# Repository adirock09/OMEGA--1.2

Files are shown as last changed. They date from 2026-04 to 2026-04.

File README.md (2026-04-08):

# OMEGA--1.2<br><br>
Screenshot (135)<br><br>

This is a Custom Rp2040 Chip Based MicroPad , It has 9 Switches , a roter encode and a oled screen . We used matrix for switches so it uses less gpio pins and it has 4 layers the rotor key is used to change the layers which is displaced on the screen so in total we have  keys output 9x4=36 + 4 outputs from rotor = 40 Outputs.
## Features

- Based on RP2040 Chip
- Has total 40 Outputs
## Firmware
- Firmware is based on QMK.
### Schematic<br><br>
Screenshot (141)<br><br>

###  PCB Design<br><br>
Screenshot (133)<br><br>
### Case<br><br>
Screenshot (140)

<br><br>

### 3D Design<br><br>
Screenshot (136)
Screenshot (137)
Screenshot (135)<br><br>

#  Bill of Materials (BOM)

##  DigiKey Components

| Qty | Manufacturer Part Number | Description | Unit Price (USD) | Total (USD) |
|-----|---|---|---|---|
| 2 | C0402C105K9PACTU | 1µF 6.3V X5R Capacitor (0402) | 0.08000 | 0.16 |
| 11 | 0402B104K160CT | 0.1µF 16V X7R Capacitor (0402) | 0.00300 | 0.03 |
| 2 | LMK107BBJ106MALT | 10µF 10V X5R Capacitor (0603) | 0.08000 | 0.16 |
| 2 | CL05C330JB5NNNC | 33pF 50V C0G Capacitor (0402) | 0.10000 | 0.20 |
| 1 | USB4215-03-A | USB Type-C Receptacle (USB 2.0) | 0.49000 | 0.49 |
| 2 | RC0402FR-075K1L | 5.1KΩ 1% Resistor (0402) | 0.10000 | 0.20 |
| 2 | ERA-2AEB273X | 27KΩ 0.1% Resistor (0402) | 0.10000 | 0.20 |
| 1 | 18996 | 0.91" OLED Display Module | 1.95 | 1.95 |
| 2 | RMCF0603FT1K00 | 1KΩ 1% Resistor (0603) | 0.10000 | 0.20 |
| 1 | RC0201FR-0710KL | 10KΩ 1% Resistor (0201) | 0.10000 | 0.10 |
| 1 | SW-PB9-AB00AQE-5 | Subminiature Pushbutton Switch | 3.39000 | 3.39 |
| 1 | SC0914(13) | RP2040 Microcontroller (QFN-56) | 0.70000 | 0.70 |
| 1 | MCP1700T-3302E/TT | 3.3V 250mA Linear Voltage Regulator | 0.51000 | 0.51 |
| 1 | AT24CS02-SSHM-T | 2Kbit I2C EEPROM | 0.31000 | 0.31 |
| 1 | STDCRA3-8M | 8MHz SMD Crystal | 0.84000 | 0.84 |
| 1 | 183031570409 | M3 Hex Socket Cap Screw | 5.05000 | 5.05 |
| 1 | 5009 | DSA Keycap Set (MX Compatible) | 5.95000 | 5.95 |
| 5 | DV-M30-TH | M3 Heat-Set Thread Insert | 0.18200 | 0.91 |
| 9 | MX2A-71NW | Cherry MX Silent Red Switch | 1.95000 | 17.55 |
| 10 | 1N4148 | Signal Diode 100V 200mA | 0.03900 | 0.39 |
| 1 | 6071183 | Rotary Encoder (BCG13 Series) | 2.44000 | 2.44 |

---

##  Manufacturing & Shipping

| Item | Cost (USD) |
|---|---|
| DigiKey Shipping  | 20.00 |
| JLCPCB – PCB Fabrication + Stencil | 7.01 |
| JLCPCB Shipping - Coupons | 8.16 |

---

#  Total Project Cost

| Category | Cost (USD) |
|---|---|
| DigiKey Components | 41.73 |
| DigiKey Shipping | 20.00 |
| JLCPCB PCB + Stencil | 7.01 |
| JLCPCB Shipping - Coupons | 8.16|
| **Grand Total** | **76.9 USD** |

---

##  Final Total: **$76.9 USD**

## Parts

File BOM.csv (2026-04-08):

Category | Quantity | Manufacturer Part Number | Description | Supplier | Unit Price (USD) | Total (USD)
Component | 2 | C0402C105K9PACTU | 1µF 6.3V X5R Capacitor (0402) | DigiKey.in | 0.08 | 0.16
Component | 11 | 0402B104K160CT | 0.1µF 16V X7R Capacitor (0402) | DigiKey.in | 0.003 | 0.03
Component | 2 | LMK107BBJ106MALT | 10µF 10V X5R Capacitor (0603) | DigiKey.in | 0.08 | 0.16
Component | 2 | CL05C330JB5NNNC | 33pF 50V C0G Capacitor (0402) | DigiKey.in | 0.1 | 0.2
Component | 1 | USB4215-03-A | USB Type-C Receptacle (USB 2.0) | DigiKey.in | 0.49 | 0.49
Component | 2 | RC0402FR-075K1L | 5.1KΩ 1% Resistor (0402) | DigiKey.in | 0.1 | 0.2
Component | 2 | ERA-2AEB273X | 27KΩ 0.1% Resistor (0402) | DigiKey.in | 0.1 | 0.2
Component | 2 | RMCF0603FT1K00 | 1KΩ 1% Resistor (0603) | DigiKey.in | 0.1 | 0.2
Component | 1 | 18996 | 0.91 inch OLED Display Module | robu.in | 1.95 | 1.95
Component | 1 | RC0201FR-0710KL | 10KΩ 1% Resistor (0201) | DigiKey.in | 0.1 | 0.1
Component | 1 | SW-PB9-AB00AQE-5 | Subminiature Pushbutton Switch | DigiKey.in | 3.39 | 3.39
Component | 1 | SC0914(13) | RP2040 Microcontroller (QFN-56) | DigiKey.in | 0.7 | 0.7
Component | 1 | MCP1700T-3302E/TT | 3.3V 250mA Linear Voltage Regulator | DigiKey.in | 0.51 | 0.51
Component | 1 | AT24CS02-SSHM-T | 2Kbit I2C EEPROM | DigiKey.in | 0.31 | 0.31
Component | 1 | STDCRA3-8M | 8MHz SMD Crystal | DigiKey.in | 0.84 | 0.84
Component | 1 | 183031570409 | M3 Hex Socket Cap Screw | DigiKey.in | 5.05 | 5.05
Component | 1 | 5009 | DSA Keycap Set (MX Compatible) | DigiKey.in | 5.95 | 5.95
Component | 5 | DV-M30-TH | M3 Heat-Set Thread Insert | DigiKey.in | 0.182 | 0.91
Component | 9 | MX2A-71NW | Cherry MX Silent Red Switch | DigiKey.in | 1.95 | 17.55
Component | 10 | 1N4148 | Signal Diode 100V 200mA | DigiKey.in | 0.039 | 0.39
Component | 1 | 6071183 | Rotary Encoder (BCG13 Series) | DigiKey.in | 2.44 | 2.44
Service | 1 | DIGIKEY-SHIPPING | DigiKey Shipping - Coupon | DigiKey.in | 20 | 20
Service | 1 | JLCPCB-PCB-STENCIL | JLCPCB PCB + Stencil | JLCPCB | 7.01 | 7.01
Service | 1 | JLCPCB-SHIPPING | JLCPCB Shipping - Coupon | JLCPCB | 8.16 | 8.16
 |  |  | Grand Total |  |  | 76.9

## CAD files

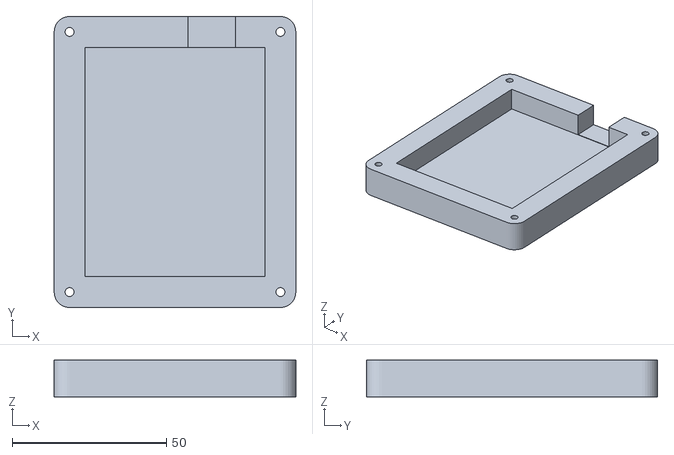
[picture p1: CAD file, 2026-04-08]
OMEGA (Custom Rp2040 Chip MicroPad)/Production/BaseLayer((O)).stl
78.4 x 94.4 x 12.0

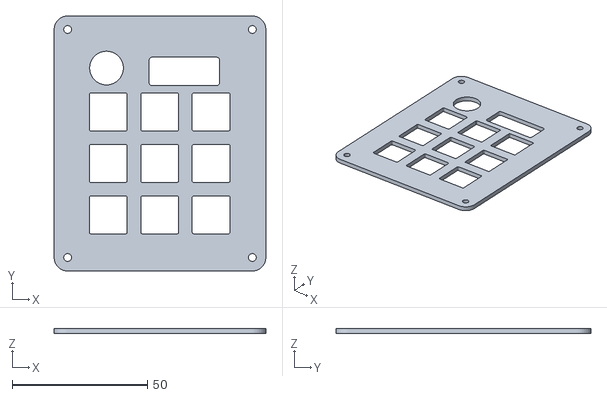
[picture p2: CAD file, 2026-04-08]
OMEGA (Custom Rp2040 Chip MicroPad)/Production/Top Layer.stl
78.4 x 94.4 x 2.00

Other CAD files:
OMEGA (Custom Rp2040 Chip MicroPad)/CAD/OMEGA.f3d

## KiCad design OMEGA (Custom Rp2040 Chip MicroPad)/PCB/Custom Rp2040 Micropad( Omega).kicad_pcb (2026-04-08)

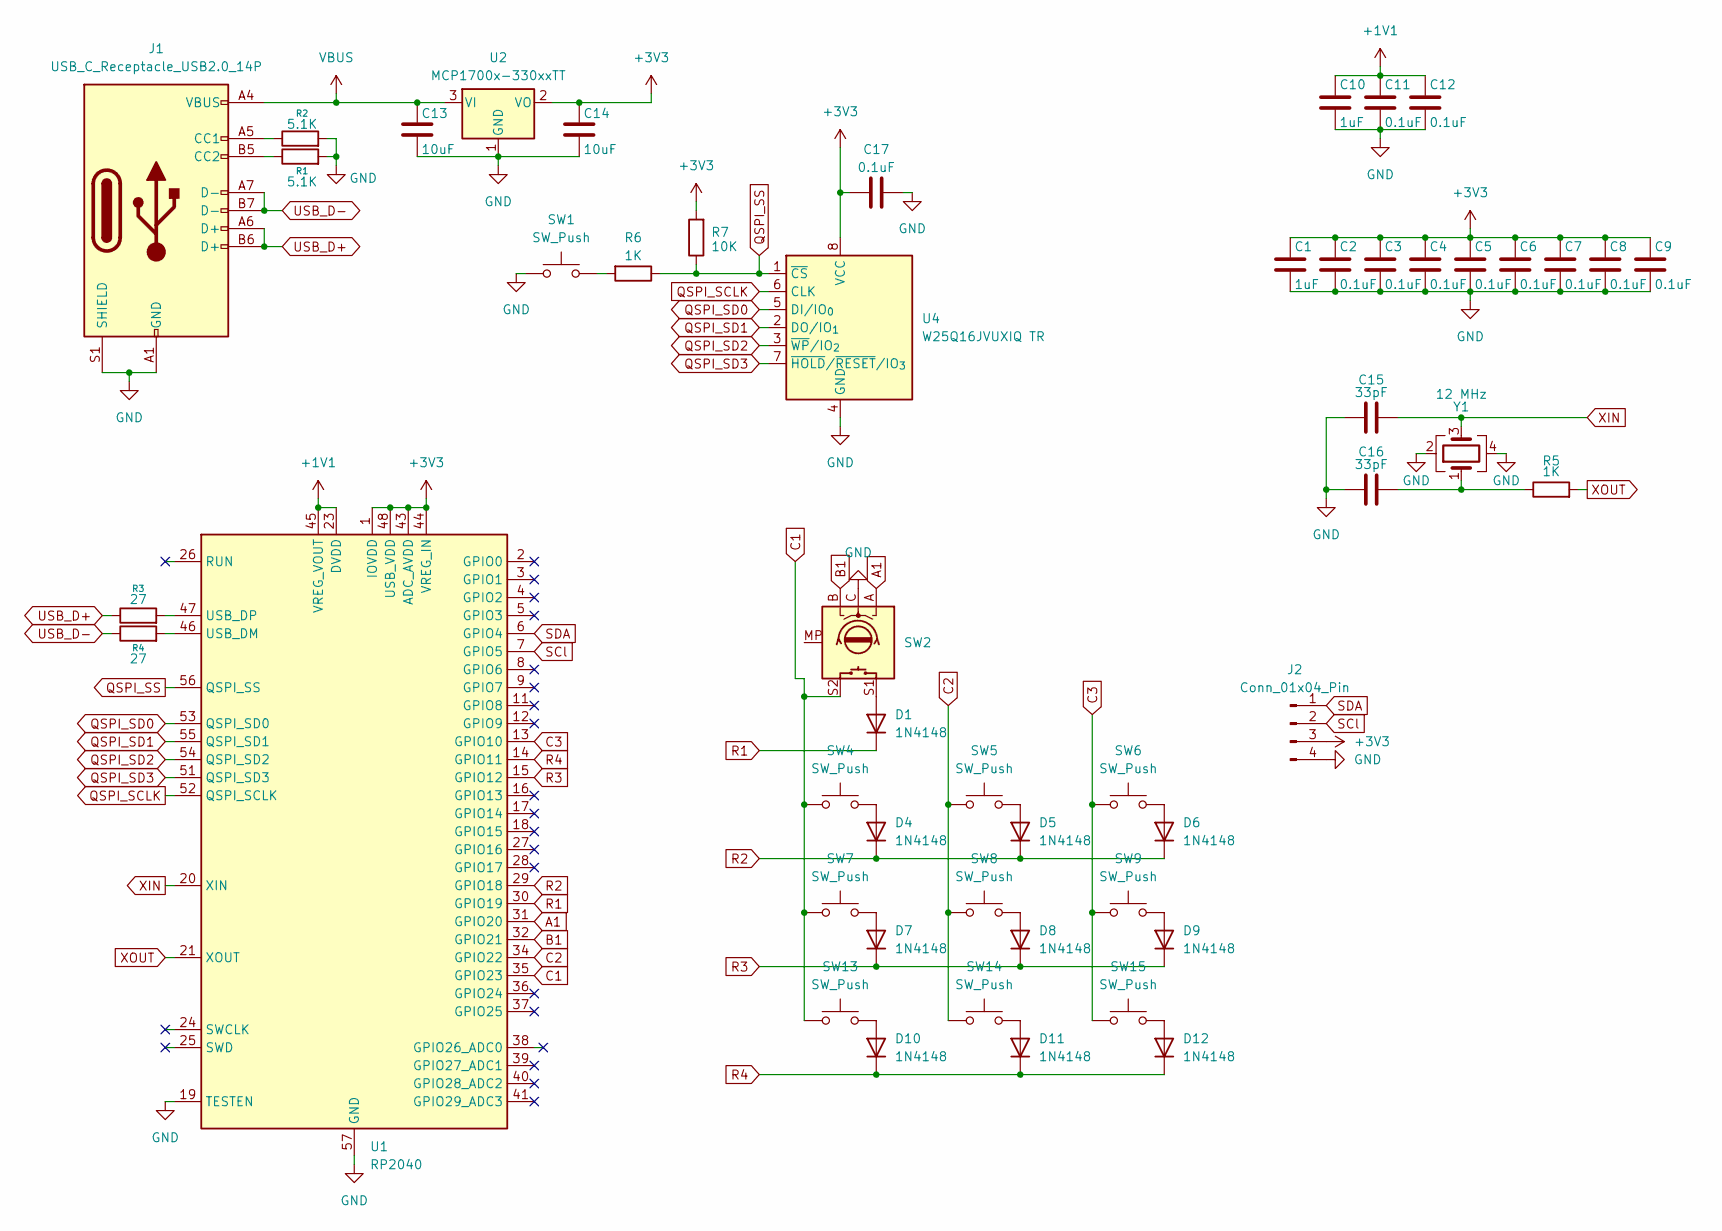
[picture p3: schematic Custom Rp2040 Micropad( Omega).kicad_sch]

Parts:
C1, C10: 1uF; C_0402_1005Metric
C2, C3, C4, C5, C6, C7, C8, C9, C11, C12, C17: 0.1uF; C_0402_1005Metric
C13, C14: 10uF; C_0603_1608Metric
C15, C16: 33pF; C_0402_1005Metric
D1, D4, D5, D6, D7, D8, D9, D10, D11, D12: 1N4148; D_DO-35_SOD27_P7.62mm_Horizontal
J1: USB_C_Receptacle_USB2.0_14P; USB_C_Receptacle_HRO_TYPE-C-31-M-12
J2: Conn_01x04_Pin; OLED_128x32
R1, R2: 5.1K; R_0402_1005Metric
R3, R4: 27; R_0402_1005Metric
R5, R6: 1K; R_0402_1005Metric
R7: 10K; R_0402_1005Metric
SW1: SW_Push; SW_Push_SPST_NO_Alps_SKRK
SW2: RotaryEncoder_Switch_MP; RotaryEncoder_Alps_EC11E-Switch_Vertical_H20mm
SW4, SW5, SW6, SW7, SW8, SW9, SW13, SW14, SW15: SW_Push; SW_Cherry_MX_1.00u_PCB
U1: RP2040; QFN-56-1EP_7x7mm_P0.4mm_EP3.2x3.2mm
U2: MCP1700x-330xxTT; SOT-23
U4: W25Q16JVUXIQ TR; Winbond_USON-8-1EP_3x2mm_P0.5mm_EP0.2x1.6mm
Y1: 12 MHz; Crystal_SMD_3225-4Pin_3.2x2.5mm

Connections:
+1V1: C10.1, C11.1, C12.1, U1.23 (DVDD), U1.45 (VREG_VOUT), U1.50 (DVDD)
+3V3: C1.1, C2.1, C3.1, C4.1, C5.1, C6.1, C7.1, C8.1, C9.1, C14.1, C17.1, J2.3, R7.2, U1.1 (IOVDD), U1.10 (IOVDD), U1.22 (IOVDD), U1.33 (IOVDD), U1.42 (IOVDD), U1.43 (ADC_AVDD), U1.44 (VREG_IN), U1.48 (USB_VDD), U1.49 (IOVDD), U2.2 (VO), U4.8 (VCC)
A1: SW2.A, U1.31 (GPIO20)
B1: SW2.B, U1.32 (GPIO21)
C1: SW2.S2, SW4.1, SW7.1, SW13.1, U1.35 (GPIO23)
C2: SW5.1, SW8.1, SW14.1, U1.34 (GPIO22)
C3: SW6.1, SW9.1, SW15.1, U1.13 (GPIO10)
GND: C1.2, C2.2, C3.2, C4.2, C5.2, C6.2, C7.2, C8.2, C9.2, C10.2, C11.2, C12.2, C13.2, C14.2, C15.1, C16.1, C17.2, J1.A1 (GND), J1.A12 (GND), J1.B1 (GND), J1.B12 (GND), J1.S1 (SHIELD), J2.4, R1.2, R2.2, SW1.1, SW2.C, U1.19 (TESTEN), U1.57 (GND), U2.1 (GND), U4.4 (GND), Y1.2, Y1.4
unnamed: C16.2, R5.1, Y1.1
unnamed: D1.2 (A), SW2.S1
unnamed: D4.2 (A), SW4.2
unnamed: D5.2 (A), SW5.2
unnamed: D6.2 (A), SW6.2
unnamed: D7.2 (A), SW7.2
unnamed: D8.2 (A), SW8.2
unnamed: D9.2 (A), SW9.2
unnamed: D10.2 (A), SW13.2
unnamed: D11.2 (A), SW14.2
unnamed: D12.2 (A), SW15.2
unnamed: J1.A5 (CC1), R2.1
unnamed: J1.B5 (CC2), R1.1
unnamed: R6.2, SW1.2
unnamed: R4.2, U1.46 (USB_DM)
unnamed: R3.2, U1.47 (USB_DP)
QSPI_SCLK: U1.52 (QSPI_SCLK), U4.6 (CLK)
QSPI_SD0: U1.53 (QSPI_SD0), U4.5 (DI/IO_{0})
QSPI_SD1: U1.55 (QSPI_SD1), U4.2 (DO/IO_{1})
QSPI_SD2: U1.54 (QSPI_SD2), U4.3 (~WP/IO_{2})
QSPI_SD3: U1.51 (QSPI_SD3), U4.7 (~HOLD/~RESET/IO_{3})
QSPI_SS: R6.1, R7.1, U1.56 (QSPI_SS), U4.1 (~CS)
R1: D1.1 (K), U1.30 (GPIO19)
R2: D4.1 (K), D5.1 (K), D6.1 (K), U1.29 (GPIO18)
R3: D7.1 (K), D8.1 (K), D9.1 (K), U1.15 (GPIO12)
R4: D10.1 (K), D11.1 (K), D12.1 (K), U1.14 (GPIO11)
SCl: J2.2, U1.7 (GPIO5)
SDA: J2.1, U1.6 (GPIO4)
USB_D+: J1.A6 (D+), J1.B6 (D+), R3.1
USB_D-: J1.A7 (D-), J1.B7 (D-), R4.1
VBUS: C13.1, J1.A4 (VBUS), J1.A9 (VBUS), J1.B4 (VBUS), J1.B9 (VBUS), U2.3 (VI)
XIN: C15.2, U1.20 (XIN), Y1.3
XOUT: R5.2, U1.21 (XOUT)

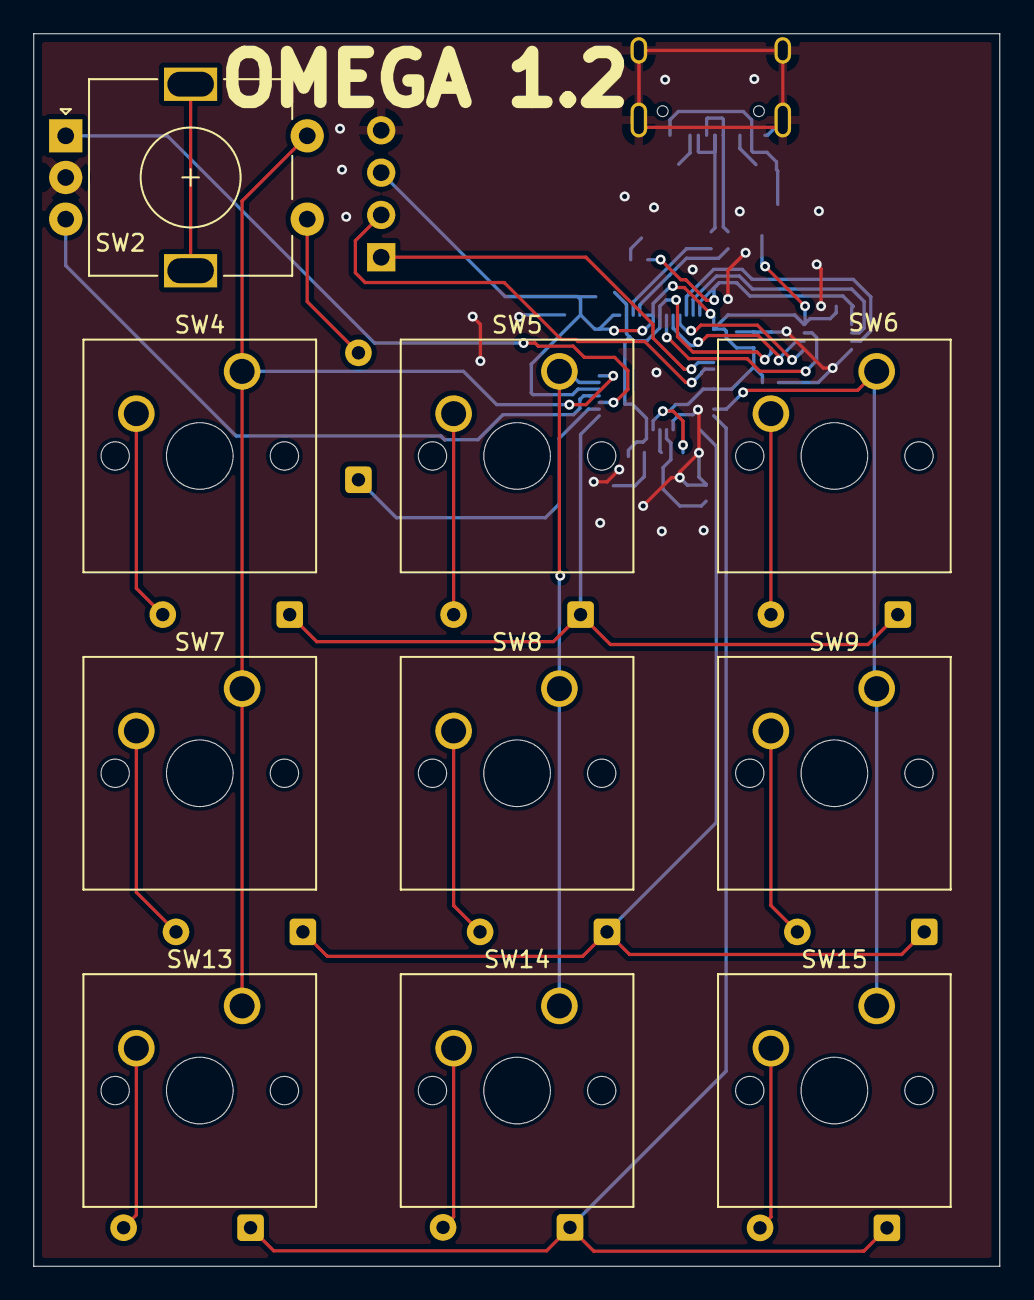
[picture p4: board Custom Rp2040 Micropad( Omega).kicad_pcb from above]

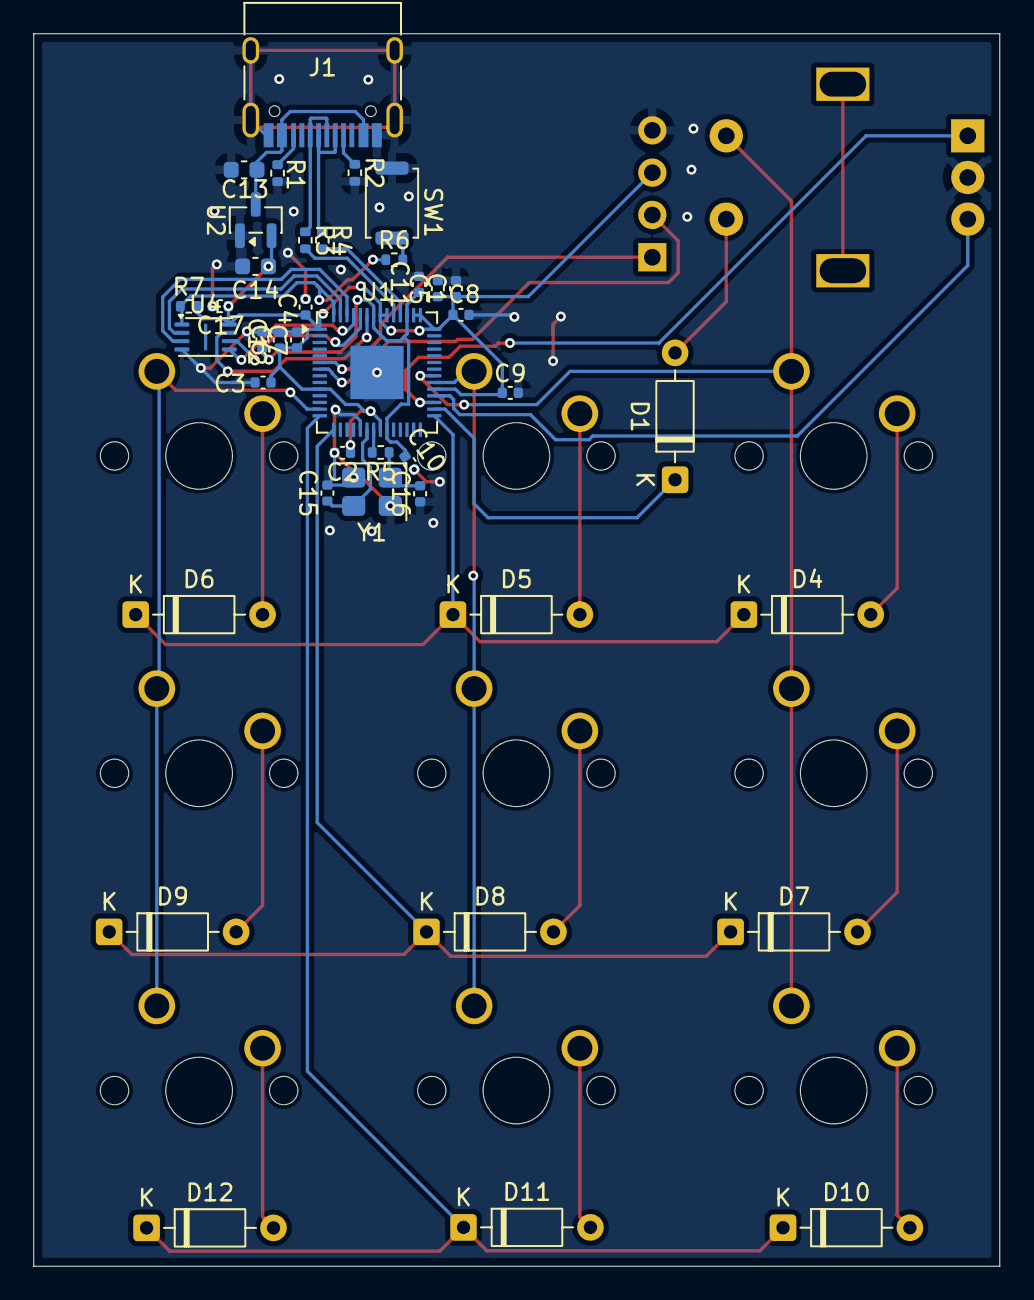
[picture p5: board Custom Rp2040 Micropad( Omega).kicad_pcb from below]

Board: 2 copper layers, 58.0 x 74.0 mm, 51 parts (40 on the bottom side), 41 nets.

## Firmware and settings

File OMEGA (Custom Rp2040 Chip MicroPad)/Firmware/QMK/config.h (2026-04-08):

#pragma once

#define MATRIX_ROWS 4
#define MATRIX_COLS 3

#define MATRIX_ROW_PINS { GP19, GP18, GP12, GP11 }
#define MATRIX_COL_PINS { GP23, GP22, GP10 }

#define DIODE_DIRECTION COL2ROW

// Encoder
#define ENCODERS_PAD_A { GP20 }
#define ENCODERS_PAD_B { GP21 }

// OLED I2C
#define I2C_DRIVER I2CD0
#define I2C1_SDA_PIN GP4
#define I2C1_SCL_PIN GP5

#define OLED_TIMEOUT 0
#define OLED_BRIGHTNESS 120

#define MOUSEKEY_DELAY 0
#define MOUSEKEY_INTERVAL 16
#define MOUSEKEY_MAX_SPEED 5
#define MOUSEKEY_TIME_TO_MAX 64
